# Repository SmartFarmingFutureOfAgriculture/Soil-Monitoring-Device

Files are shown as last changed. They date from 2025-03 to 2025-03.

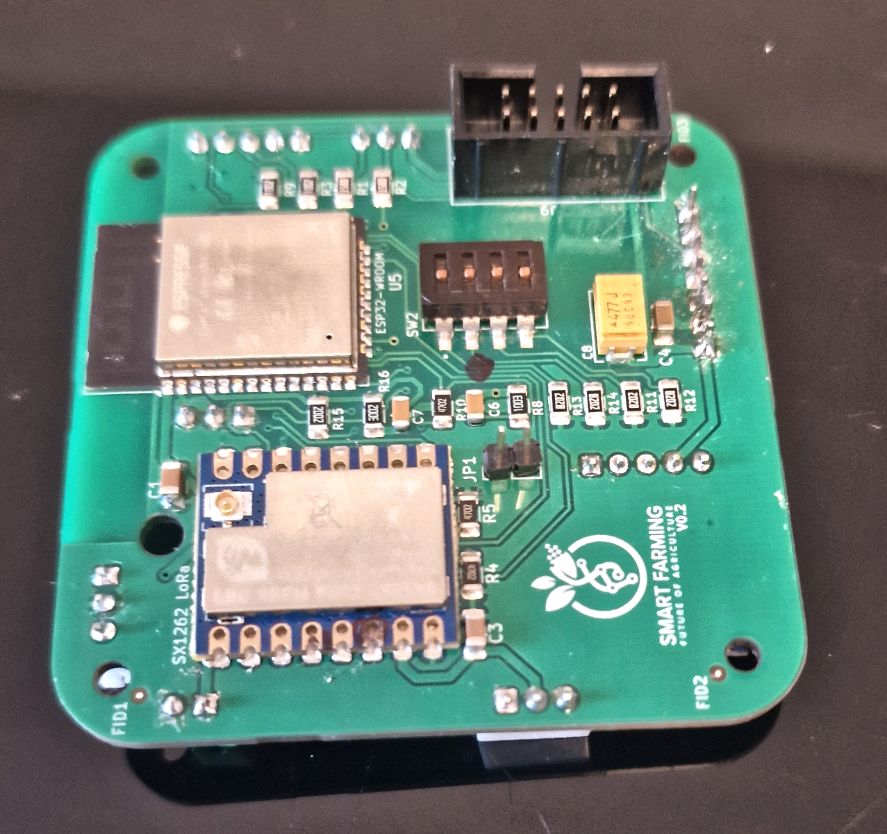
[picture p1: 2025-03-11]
hardware/gateway/5-Sensor-Node-Gateway-Top.jpg

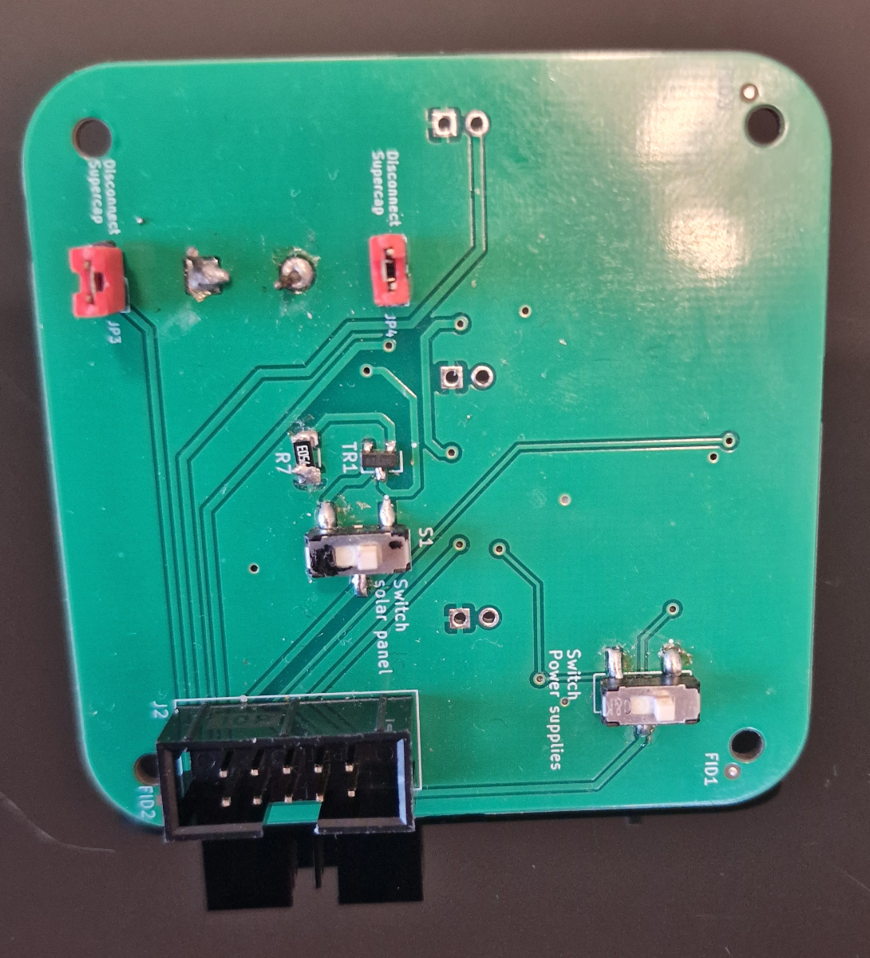
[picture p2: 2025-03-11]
hardware/power-supply/4-Power-Supply-Bottom.jpg

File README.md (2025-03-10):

# Smart Farming Soil Monitoring Device
This is an **open-source soil monitoring system** designed to measure NPK levels, temperature, moisture, and conductivity.

🚧 **Project Status: In Development** 🚧  
This project is still in the **development phase** and may change frequently.  
Some features may not be fully implemented, and modifications are ongoing.  
Contributions and feedback are welcome!  

## License
- **Software**: GNU GPL-2.0  
- **Hardware**: CERN OHL  
- **Disclaimer**: This project is provided **"as is"**, without any warranty or liability.

## How to Contribute
Contributions are welcome! Please follow the licensing rules and give proper attribution.

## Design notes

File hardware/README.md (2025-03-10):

## 🛠️ Hardware Development Tools
The hardware design files were created using:

- **KiCAD 6.x+** (for schematics & PCB design) → [https://www.kicad.org/](https://www.kicad.org/)
- **FreeCAD** (for 3D enclosure modeling) → [https://www.freecadweb.org/](https://www.freecadweb.org/)

💡 To modify the hardware, install **KiCAD** and **FreeCAD**, then open the project files.

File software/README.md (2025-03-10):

## 🔧 Software Development Tools
This project was developed using the following software:

- **PlatformIO** (for firmware development) → [https://platformio.org/](https://platformio.org/)
- **Arduino IDE** (alternative for testing) → [https://www.arduino.cc/en/software](https://www.arduino.cc/en/software)
- **Python 3.x** (for data processing scripts) → [https://www.python.org/](https://www.python.org/)

💡 To contribute or modify the software, install **PlatformIO** and clone the repository.

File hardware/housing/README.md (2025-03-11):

The housing can be produced with a 3D printer. The hardware design files were created using:

    FreeCAD (for 3D enclosure modeling) → https://www.freecadweb.org/

💡 To modify the hardware, install FreeCAD, then open the project files.

Smart Farming Soil Monitoring System
Copyright (C) 2024 Smart Farming gGmbH

This hardware design is released under the CERN Open Hardware License (CERN OHL).
You are free to use, modify, and distribute it under the terms of this license.
NO WARRANTY: This hardware is provided "as is", without any warranty of any kind.
The developer assumes no liability for damages resulting from its use.

For full license details, visit: https://ohwr.org/project/cernohl/wikis/home

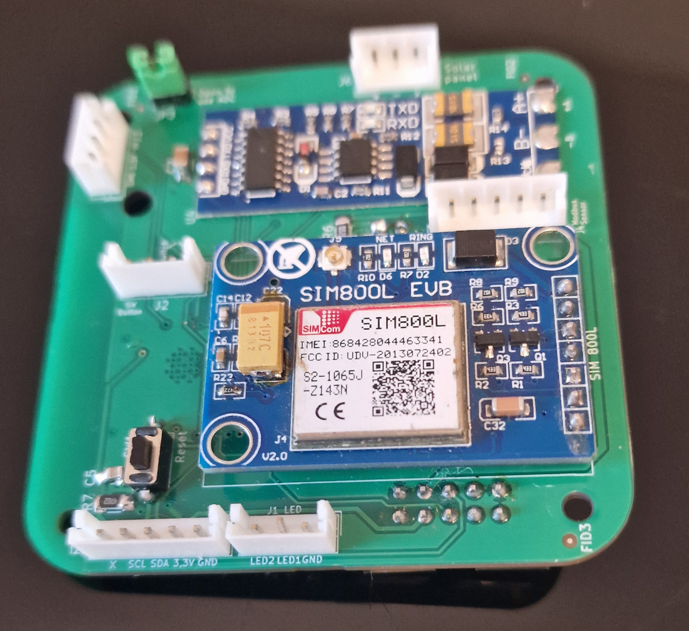
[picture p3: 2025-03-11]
hardware/gateway/6-Sensor-Node-Gateway-Bottom.jpg

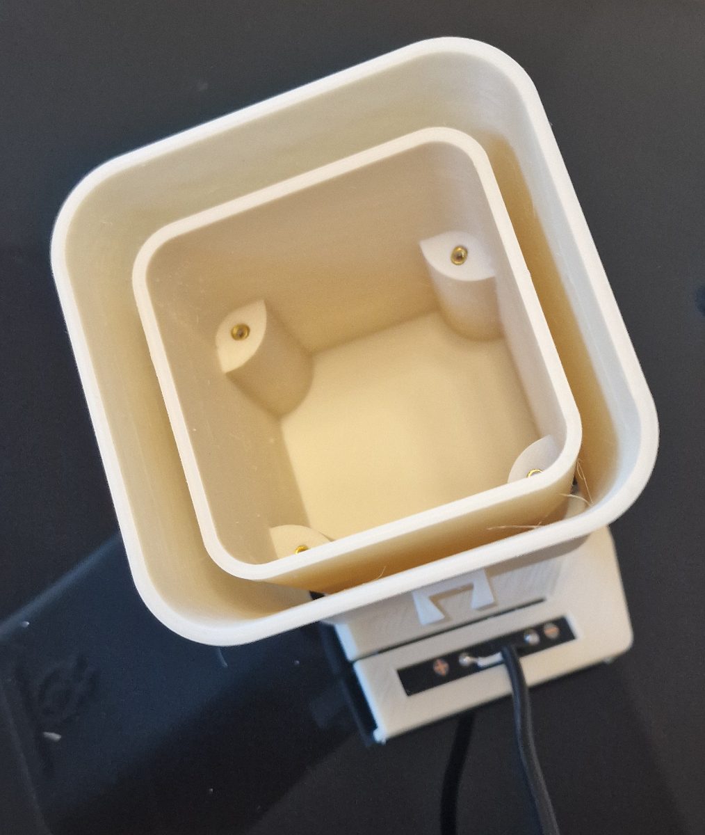
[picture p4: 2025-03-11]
hardware/housing/2-Housing-bottom.jpg

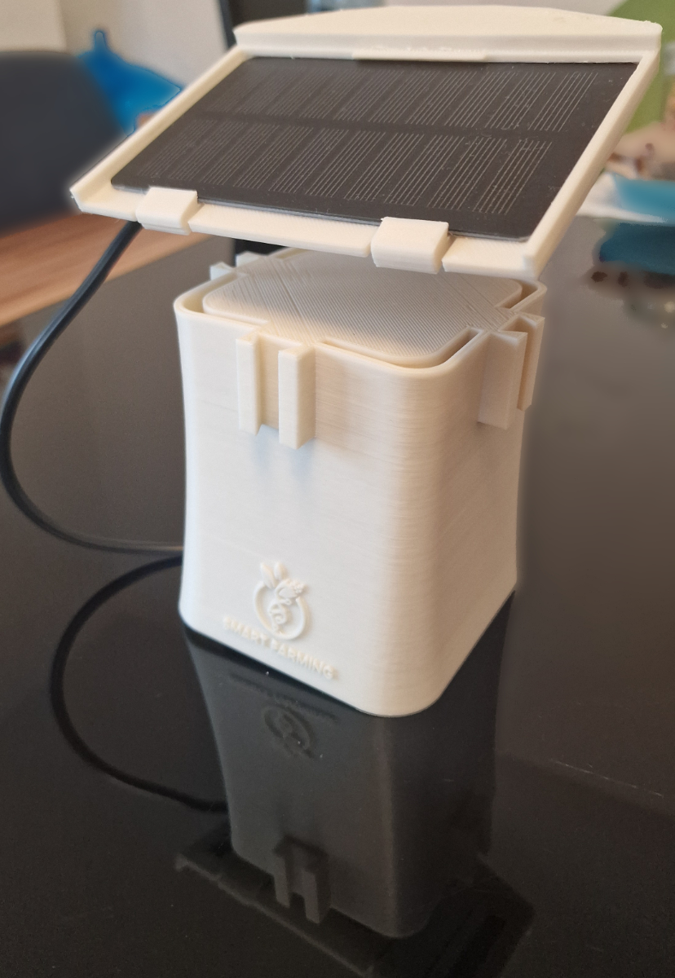
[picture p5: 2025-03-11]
hardware/housing/1-Housing.jpg

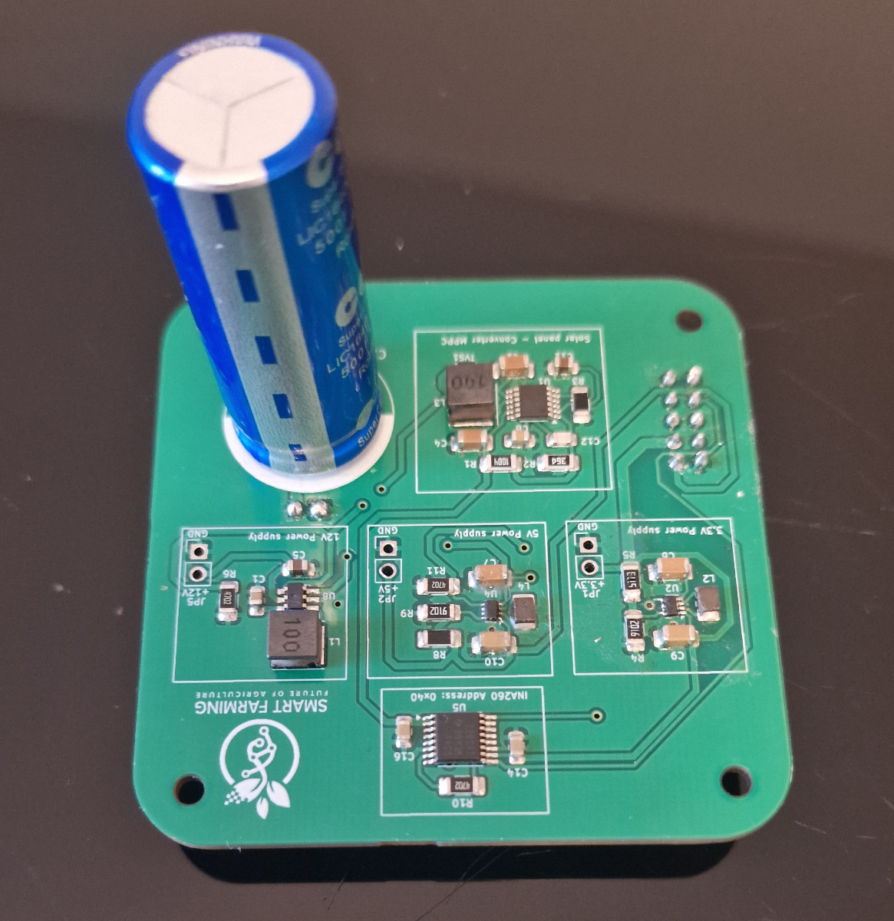
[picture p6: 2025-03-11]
hardware/power-supply/3-Power-Supply-Top.jpg

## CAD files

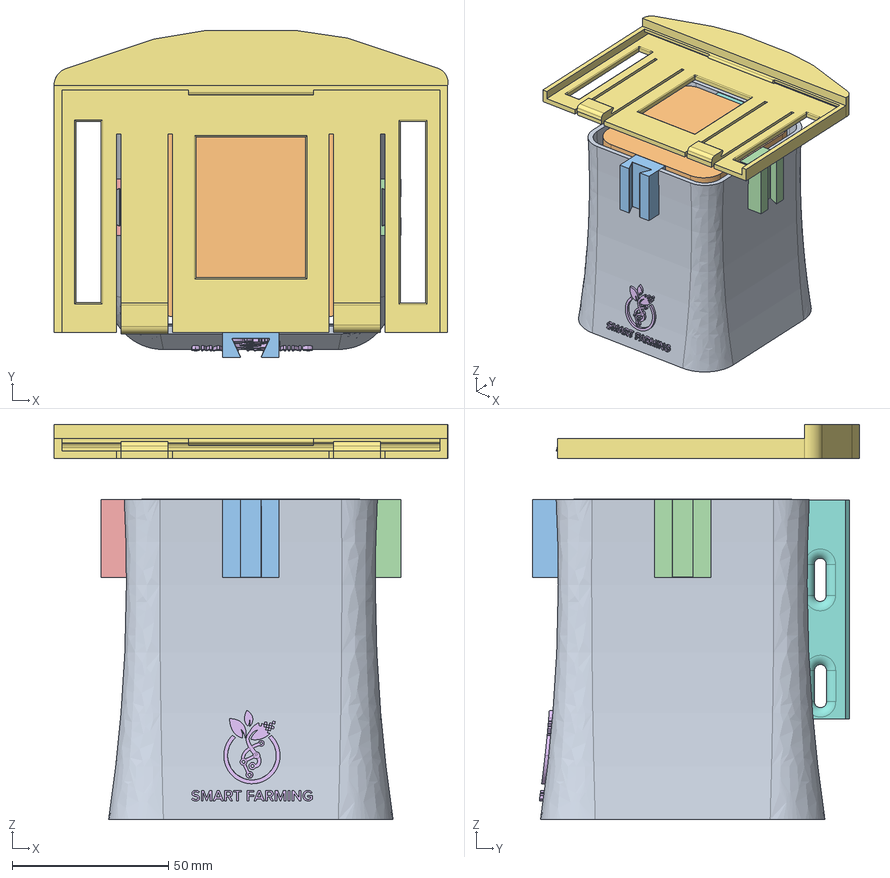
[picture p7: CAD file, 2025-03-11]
hardware/housing/Housing-Field-Sensor-Fixed-Solar-Holder.FCStd
126.1 x 104.5 x 126.5 mm
OuterContainer
InnerContainer
Projektionsobjekt_Logo
SolarHolder
Cut001_HousingHolder

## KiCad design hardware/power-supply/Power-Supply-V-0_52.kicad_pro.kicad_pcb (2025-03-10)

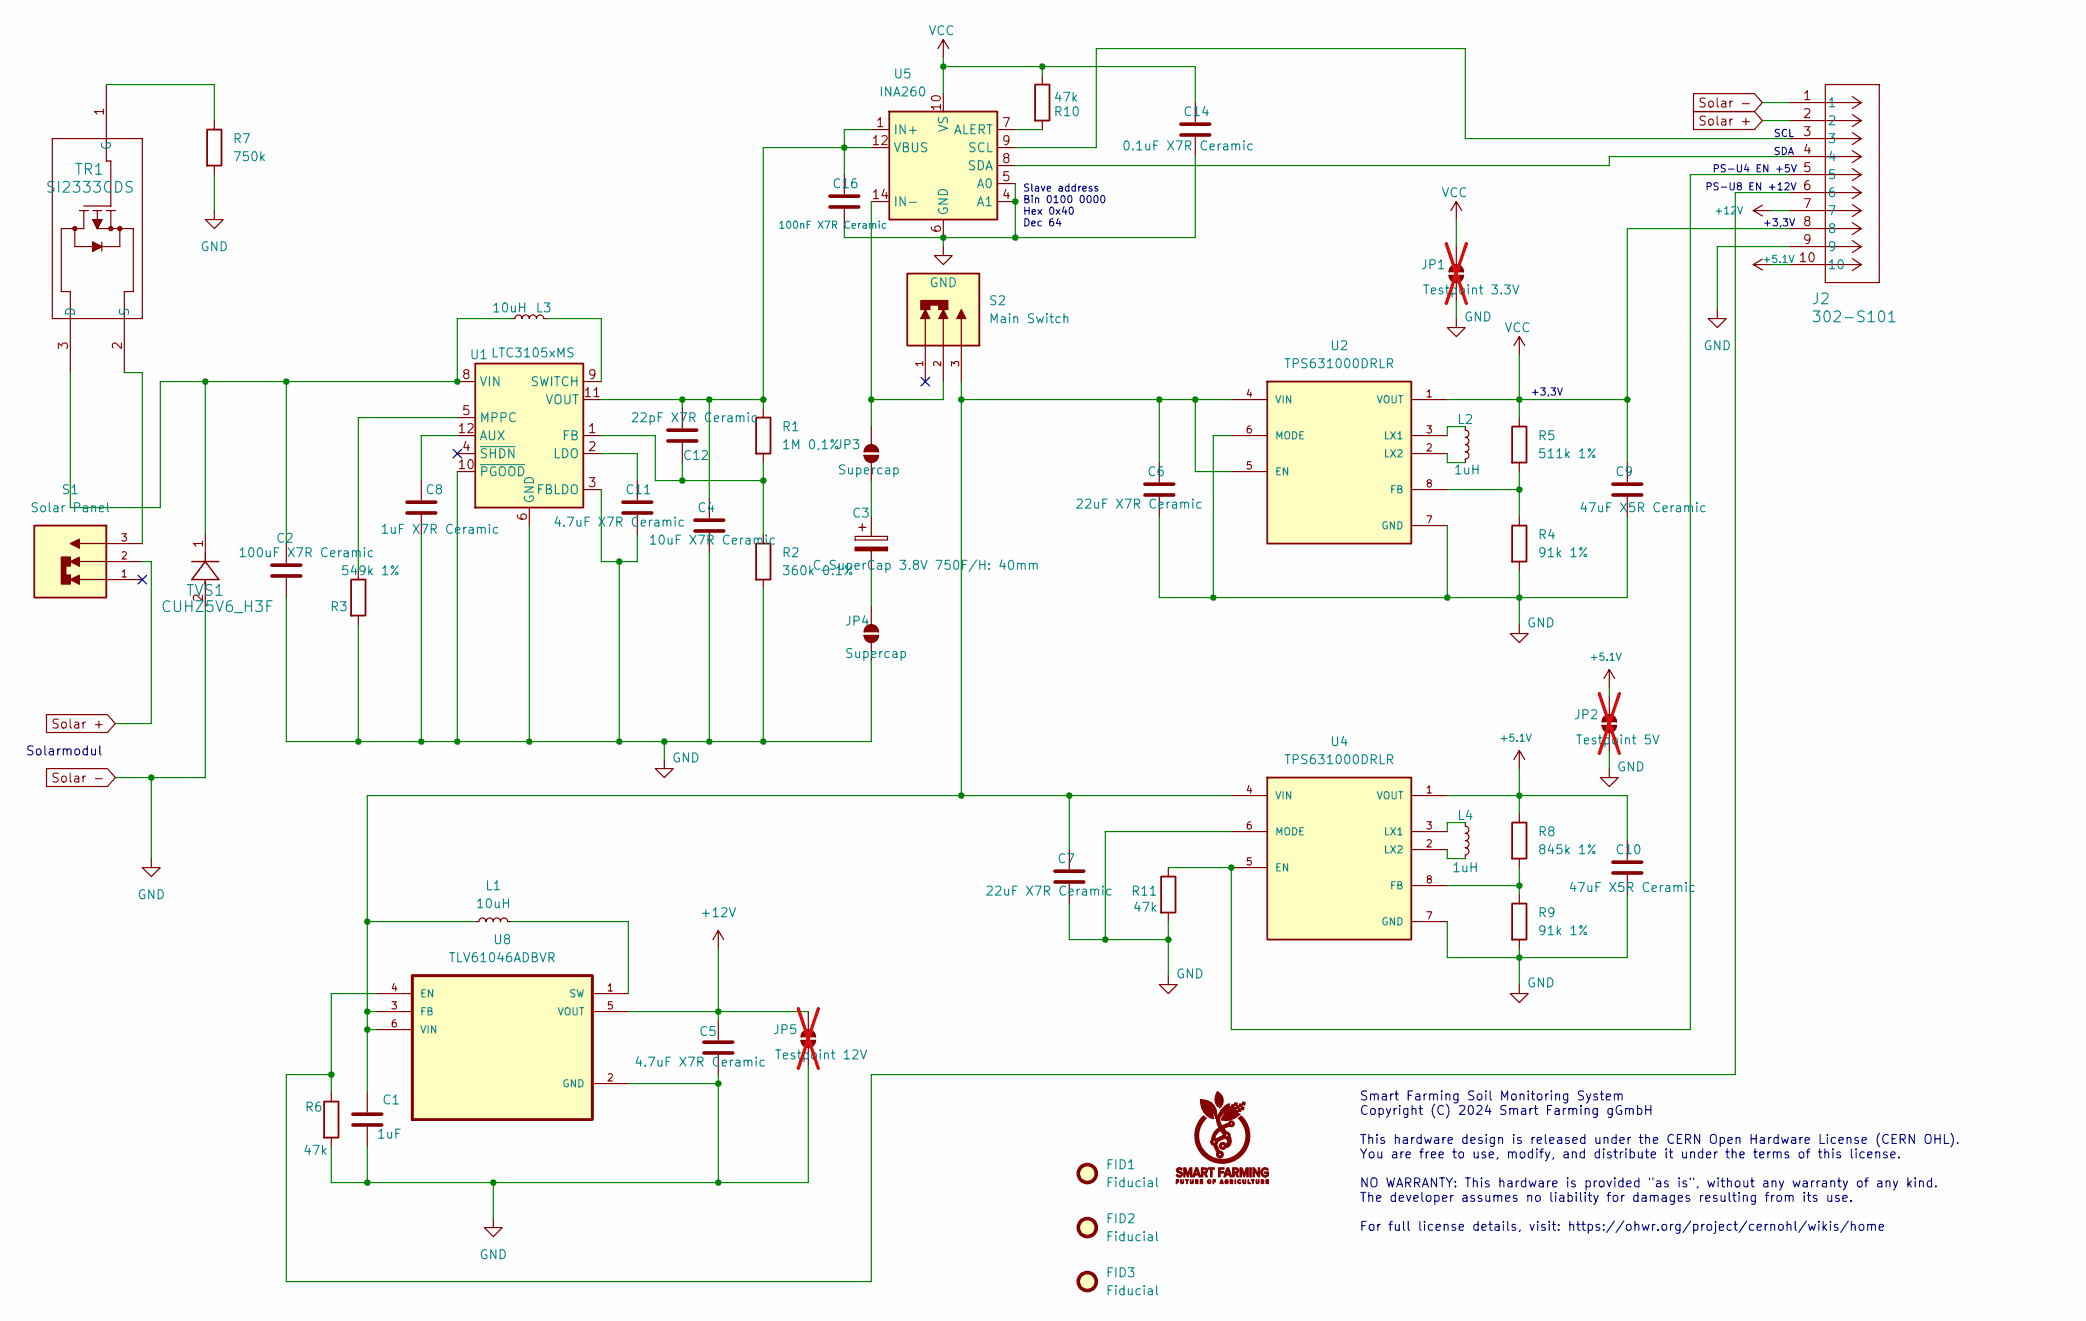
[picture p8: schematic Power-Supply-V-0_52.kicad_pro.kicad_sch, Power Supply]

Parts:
C1: 1uF; C_0805_2012Metric_Pad1.18x1.45mm_HandSolder
C2: 100uF X7R Ceramic; C_1206_3216Metric_Pad1.33x1.80mm_HandSolder
C3: C_SuperCap 3.8V 750F/H: 40mm; CP_Radial_D18.0mm_P7.50mm
C4: 10uF X7R Ceramic; C_1206_3216Metric_Pad1.33x1.80mm_HandSolder
C5, C11: 4.7uF X7R Ceramic; C_0805_2012Metric_Pad1.18x1.45mm_HandSolder
C6, C7: 22uF X7R Ceramic; C_1206_3216Metric_Pad1.33x1.80mm_HandSolder
C8: 1uF X7R Ceramic; C_0805_2012Metric_Pad1.18x1.45mm_HandSolder
C9, C10: 47uF X5R Ceramic; C_1206_3216Metric_Pad1.33x1.80mm_HandSolder
C12: 22pF X7R Ceramic; C_0805_2012Metric_Pad1.18x1.45mm_HandSolder
C14: 0.1uF X7R Ceramic; C_0805_2012Metric_Pad1.18x1.45mm_HandSolder
C16: 100nF X7R Ceramic; C_0805_2012Metric_Pad1.18x1.45mm_HandSolder
FID1, FID2, FID3: Fiducial; Fiducial_0.75mm_Mask1.5mm
J2: 302-S101; CONN10_302-S101_OST
JP1: Testpoint 3.3V; PinHeader_1x02_P2.54mm_Vertical; not fitted
JP2: Testpoint 5V; PinHeader_1x02_P2.54mm_Vertical; not fitted
JP3, JP4: Supercap; PinHeader_1x02_P2.54mm_Vertical
JP5: Testpoint 12V; PinHeader_1x02_P2.54mm_Vertical; not fitted
L1, L3: 10uH; L_Taiyo-Yuden_MD-5050
L2, L4: 1uH; L_1008_2520Metric_Pad1.43x2.20mm_HandSolder
R1: 1M 0,1%; R_1206_3216Metric_Pad1.30x1.75mm_HandSolder
R2: 360k 0.1%; R_1206_3216Metric_Pad1.30x1.75mm_HandSolder
R3: 549k 1%; R_1206_3216Metric_Pad1.30x1.75mm_HandSolder
R4, R9: 91k 1%; R_1206_3216Metric_Pad1.30x1.75mm_HandSolder
R5: 511k 1%; R_1206_3216Metric_Pad1.30x1.75mm_HandSolder
R6, R10, R11: 47k; R_1206_3216Metric_Pad1.30x1.75mm_HandSolder
R7: 750k; R_1206_3216Metric_Pad1.30x1.75mm_HandSolder
R8: 845k 1%; R_1206_3216Metric_Pad1.30x1.75mm_HandSolder
S1: Solar Panel; SW_JS102011SCQN; PARTREV 8 Oct 21
S2: Main Switch; SW_JS102011SCQN; PARTREV 8 Oct 21
TR1: SI2333CDS; TO-236_VIS
TVS1: CUHZ5V6_H3F; SOD-323HEUS2H_TOS
U1: LTC3105xMS; MSOP-12_3x4mm_P0.65mm
U2, U4: TPS631000DRLR; SOT-583-8; PARTREV B
U5: INA260; TSSOP-16_4.4x5mm_P0.65mm
U8: TLV61046ADBVR; SOT-23-6_Handsoldering

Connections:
+5.1V: C10.1, J2.10, JP2.2 (B), R8.1, U4.1 (VOUT)
+12V: C5.1, J2.7, JP5.2 (B), U8.5 (VOUT)
unnamed: C3.1, JP3.1 (A)
unnamed: JP3.2 (B), S2.2, U5.14 (IN-), U5.15 (IN-), U5.16 (IN-)
unnamed: C3.2, JP4.2 (B)
unnamed: C2.1, L3.1, TR1.3 (D), TVS1.1, U1.8 (VIN)
unnamed: R7.1, TR1.1 (G)
unnamed: S1.3, TR1.2 (S)
unnamed: C8.1, U1.12 (AUX)
unnamed: C12.2, R1.2, R2.1, U1.1 (FB)
unnamed: C11.1, U1.2 (LDO)
unnamed: R3.1, U1.5 (MPPC)
unnamed: L3.2, U1.9 (SWITCH)
unnamed: C4.1, C12.1, C16.1, R1.1, U1.11 (VOUT), U5.1 (IN+), U5.2 (IN+), U5.3 (IN+), U5.12 (VBUS)
unnamed: C1.1, C6.1, C7.1, L1.1, S2.3, U2.4 (VIN), U2.5 (EN), U4.4 (VIN), U8.3 (FB), U8.6 (VIN)
unnamed: R4.1, R5.2, U2.8 (FB)
unnamed: L2.1, U2.3 (LX1)
unnamed: L2.2, U2.2 (LX2)
unnamed: J2.5, R11.1, U4.5 (EN)
unnamed: R8.2, R9.1, U4.8 (FB)
unnamed: L4.1, U4.3 (LX1)
unnamed: L4.2, U4.2 (LX2)
unnamed: R10.2, U5.7 (ALERT)
unnamed: J2.3, U5.9 (SCL)
unnamed: J2.4, U5.8 (SDA)
unnamed: J2.6, R6.1, U8.4 (EN)
unnamed: L1.2, U8.1 (SW)
Solar +: J2.2, S1.2
Solar -: C1.2, C2.2, C4.2, C5.2, C6.2, C7.2, C8.2, C9.2, C10.2, C11.2, C14.2, C16.2, J2.1, J2.9, JP1.1 (A), JP2.1 (A), JP4.1 (A), JP5.1 (A), R2.2, R3.2, R4.2, R6.2, R7.2, R9.2, R11.2, TVS1.2, U1.3 (FBLDO), U1.6 (GND), U1.7 (GND), U1.10 (~PGOOD), U2.6 (MODE), U2.7 (GND), U4.6 (MODE), U4.7 (GND), U5.4 (A1), U5.5 (A0), U5.6 (GND), U5.11 (GND), U8.2 (GND)
VCC: C9.1, C14.1, J2.8, JP1.2 (B), R5.1, R10.1, U2.1 (VOUT), U5.10 (VS)

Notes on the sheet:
PS-U4 EN +5V
SCL
Smart Farming Soil Monitoring System Copyright (C) 2024 Smart Farming gGmbH This hardware design is released under the CERN Open Hardware License (CERN OHL). You are free to use, modify, and distribute it under the terms of this license. NO WARRANTY: This hardware is provided "as is", without any w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
Solarmodul
SDA
PS-U8 EN +12V
Slave address Bin 0100 0000 Hex 0x40 Dec 64
+3,3V

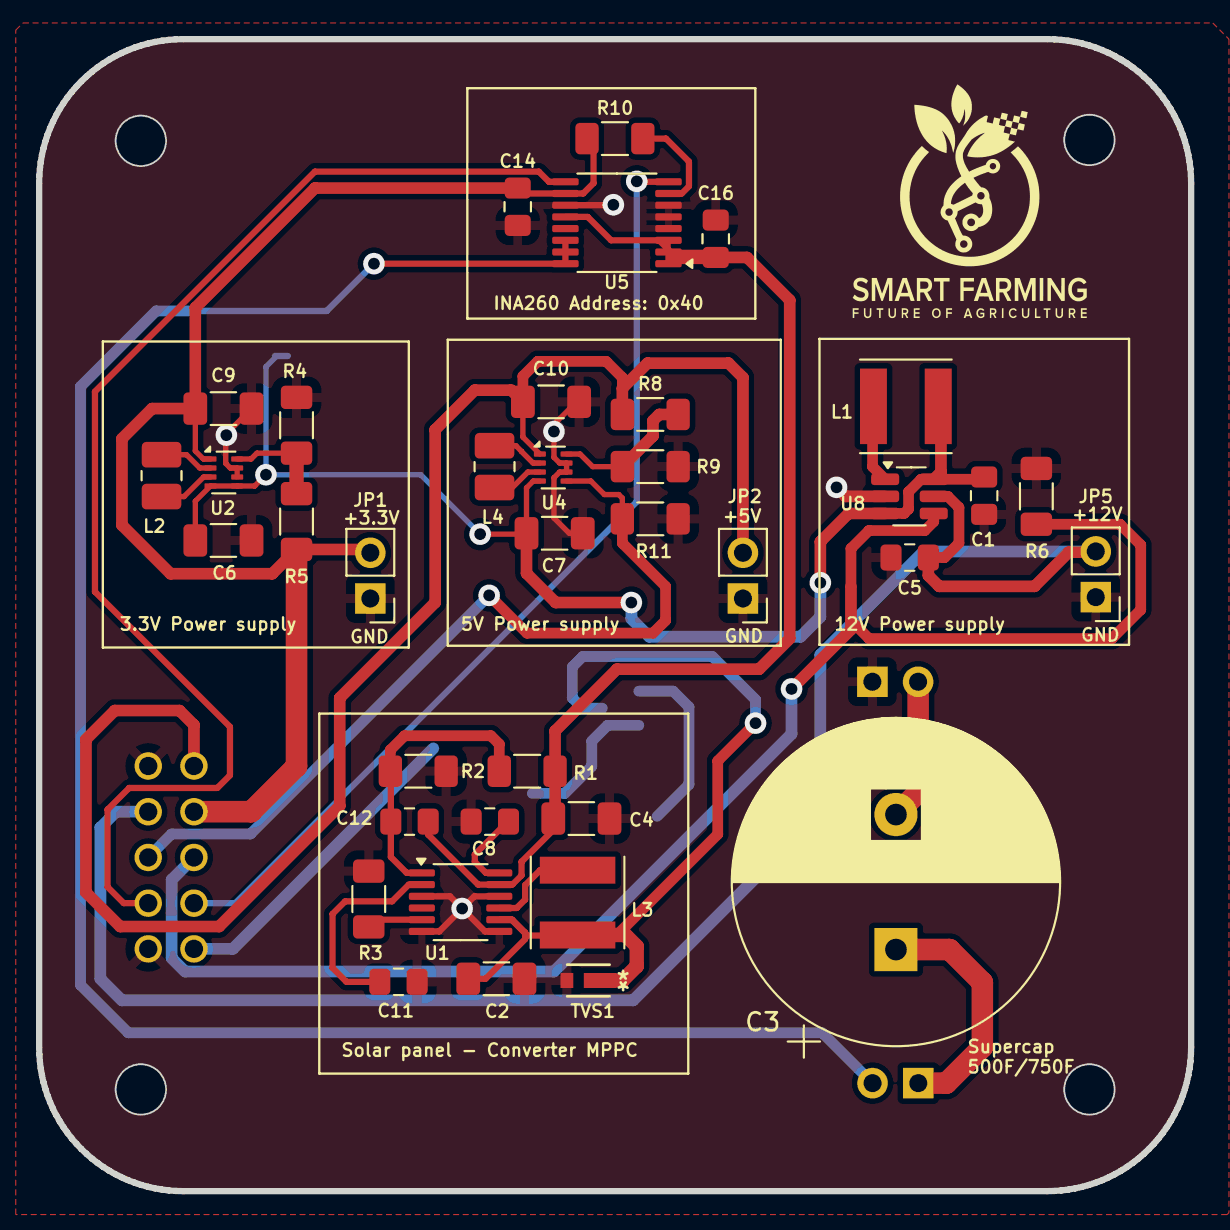
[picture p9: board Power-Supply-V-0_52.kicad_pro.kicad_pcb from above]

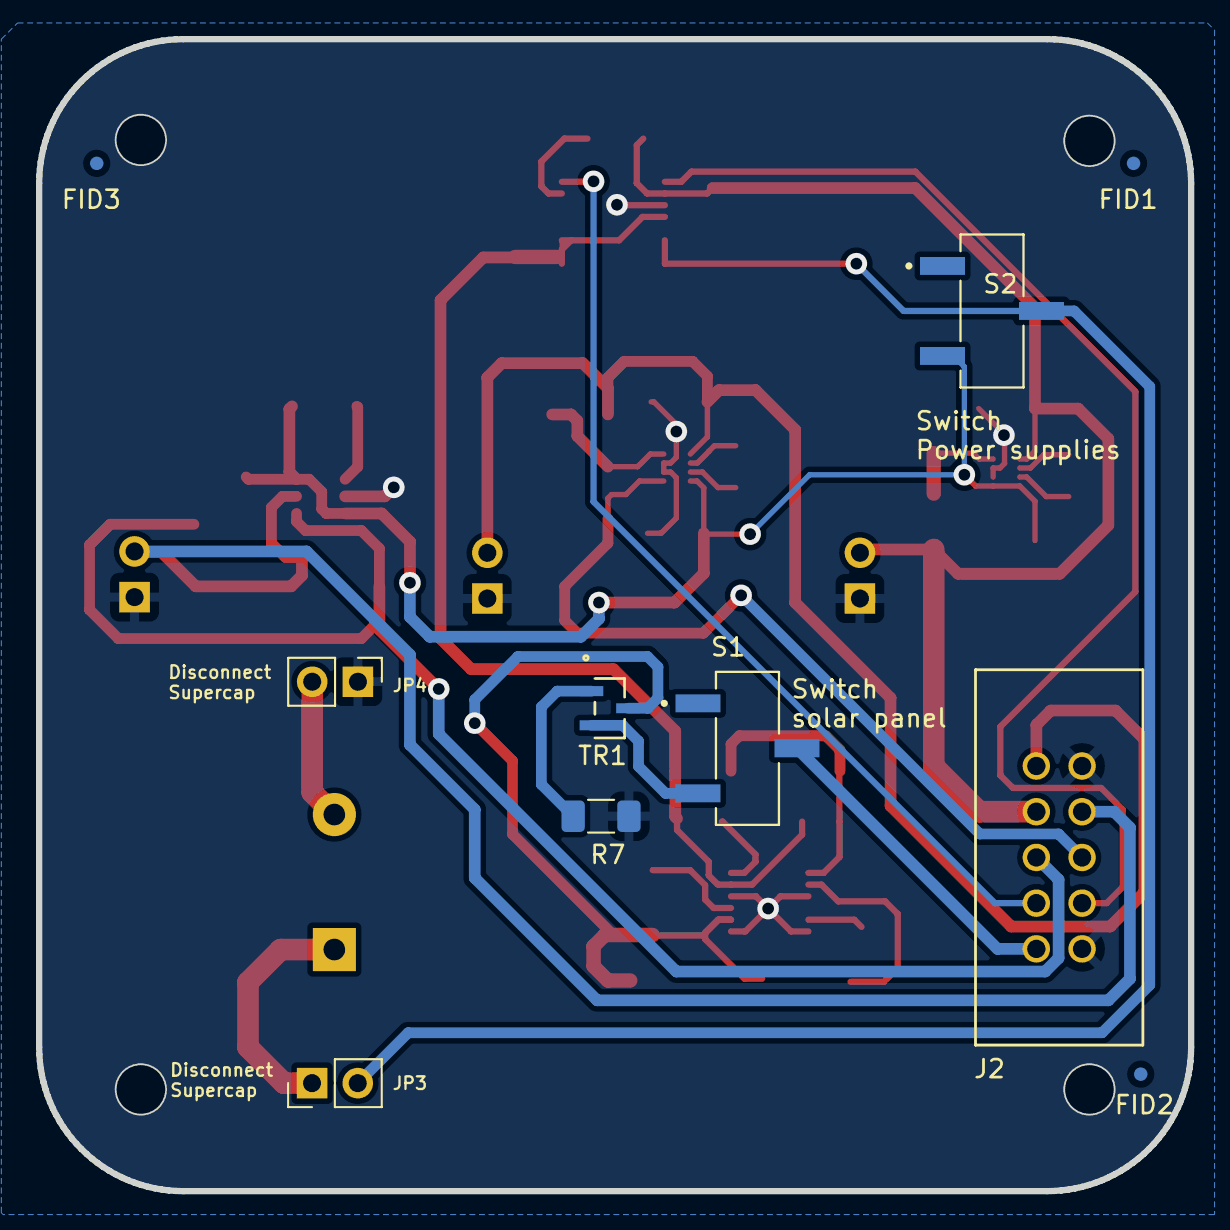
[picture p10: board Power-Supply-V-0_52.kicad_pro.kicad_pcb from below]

Board: 2 copper layers, 64.0 x 64.0 mm, 48 parts (10 on the bottom side), 30 nets.

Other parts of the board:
G**: LOGO; Logo_Smart_Farming

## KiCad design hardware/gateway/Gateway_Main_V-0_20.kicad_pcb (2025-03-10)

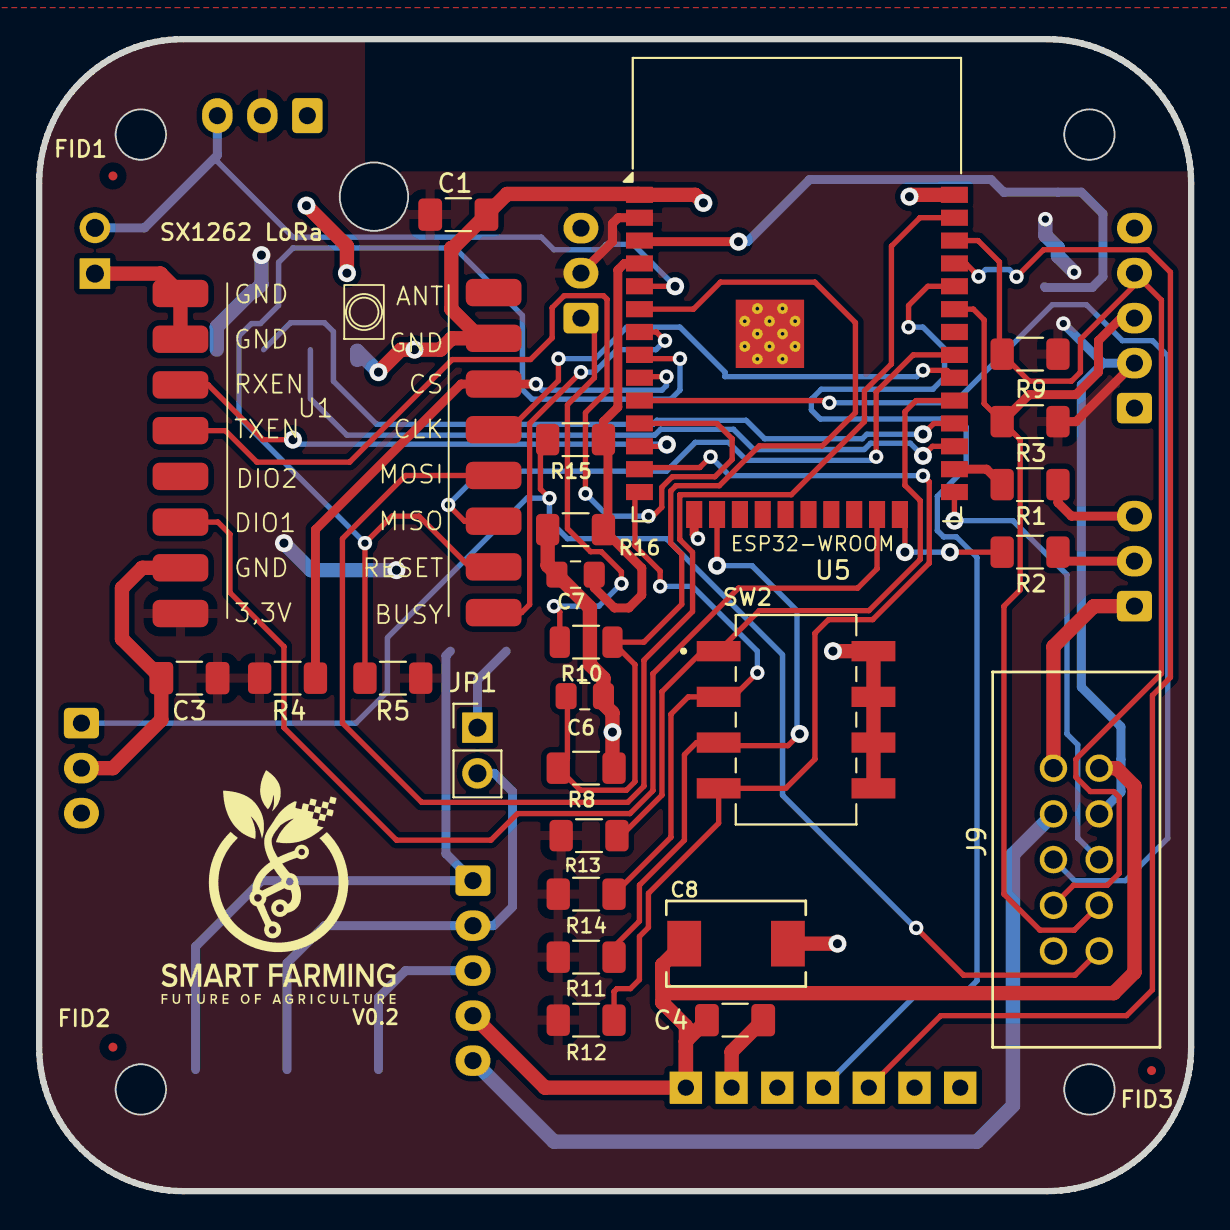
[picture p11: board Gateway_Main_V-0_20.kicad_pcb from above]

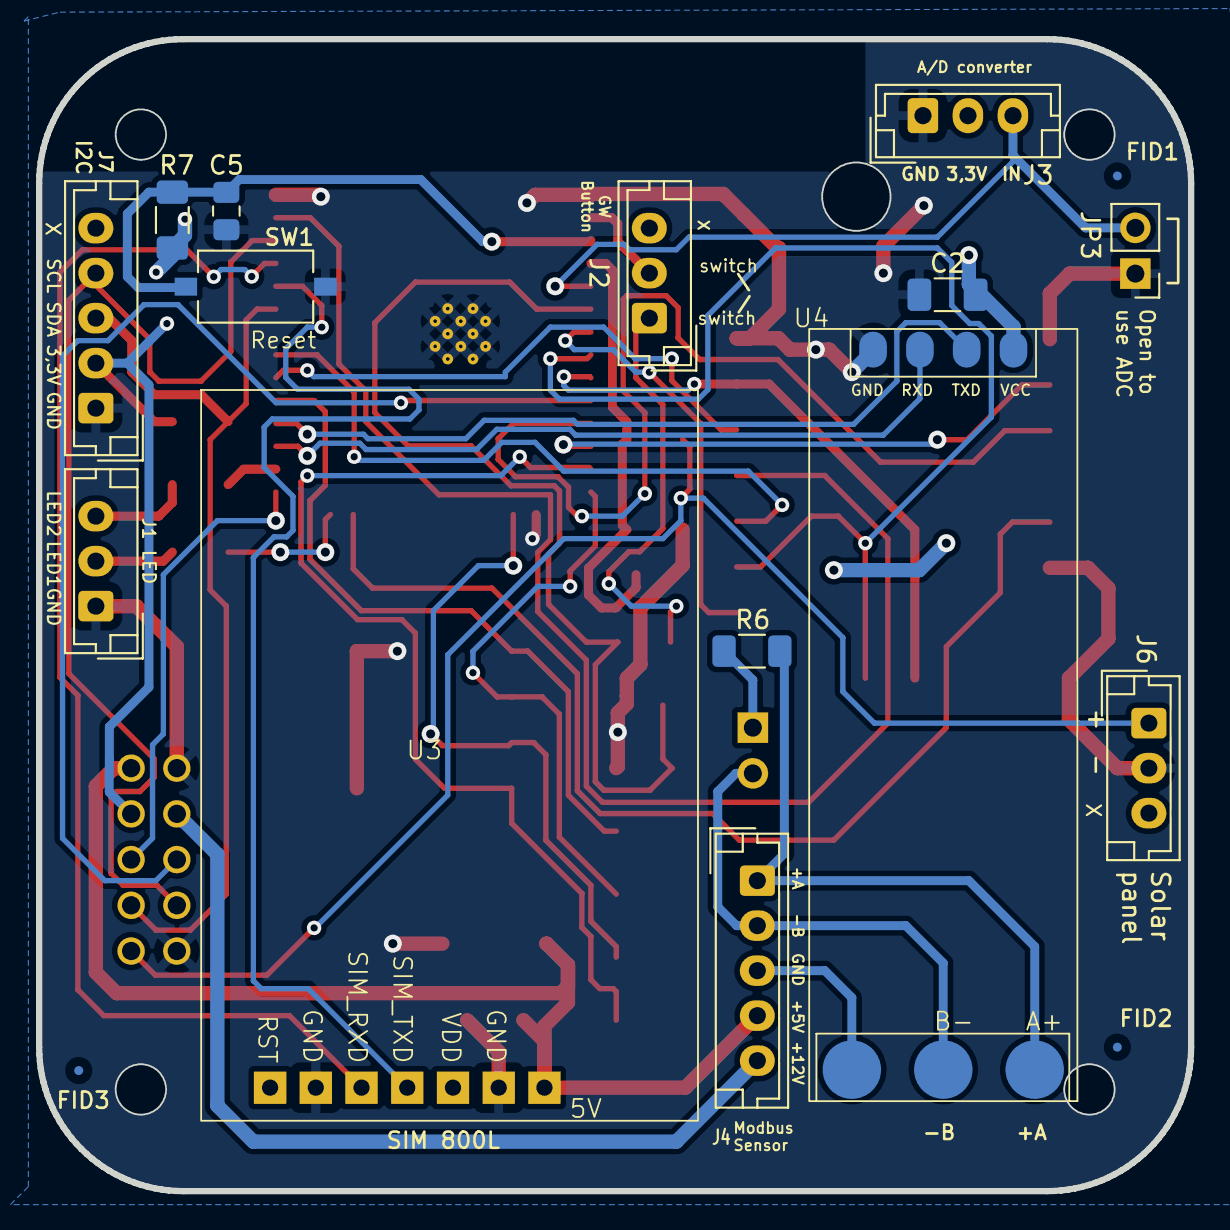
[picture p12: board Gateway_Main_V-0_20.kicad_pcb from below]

Board: 2 copper layers, 64.0 x 64.0 mm, 45 parts (17 on the bottom side), 39 nets.

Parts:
C1, C2, C3: 10uF X7R Ceramic; C_1206_3216Metric_Pad1.33x1.80mm_HandSolder
C4: 100uF; C_1206_3216Metric_Pad1.33x1.80mm_HandSolder
C5: 1uF; C_0805_2012Metric_Pad1.18x1.45mm_HandSolder
C6, C7: 0.1uF; C_0805_2012Metric_Pad1.18x1.45mm_HandSolder
C8: 470uF; TAJD_AVX
FID1, FID1#2, FID2, FID2#2, FID3, FID3#2: Fiducial; Fiducial_0.5mm_Mask1.5mm
J1: LED; JST_EH_B3B-EH-A_1x03_P2.50mm_Vertical
J2: Gateway button; JST_EH_B3B-EH-A_1x03_P2.50mm_Vertical
J3: A/D converter; JST_EH_B3B-EH-A_1x03_P2.50mm_Vertical
J4: Modbus (Sensor); JST_EH_B5B-EH-A_1x05_P2.50mm_Vertical
J6: Solar module; JST_EH_B3B-EH-A_1x03_P2.50mm_Vertical
J7: I2C; JST_EH_B5B-EH-A_1x05_P2.50mm_Vertical
J9: 302-S101; CONN10_302-S101_OST
JP1: Jumper_2_Bridged; PinHeader_1x02_P2.54mm_Vertical
JP3: ADC1_CH3; PinHeader_1x02_P2.54mm_Vertical
R1, R2: 150; R_1206_3216Metric_Pad1.30x1.75mm_HandSolder
R3, R9: 10k; R_1206_3216Metric_Pad1.30x1.75mm_HandSolder
R4, R5, R7: 47k; R_1206_3216Metric_Pad1.30x1.75mm_HandSolder
R6: 120; R_1206_3216Metric_Pad1.30x1.75mm_HandSolder
R8: 100k; R_1206_3216Metric_Pad1.30x1.75mm_HandSolder
R10: 47k; R_1206_3216Metric
R11, R12, R13, R14: 82k; R_1206_3216Metric_Pad1.30x1.75mm_HandSolder
R15: 20k 1%; R_1206_3216Metric_Pad1.30x1.75mm_HandSolder
R16: 30k 1%; R_1206_3216Metric_Pad1.30x1.75mm_HandSolder
SW1: Reset; SW_Tactile_SPST_NO_Straight_CK_PTS636Sx25SMTRLFS
SW2: SW-219-4MST; Switch-SW_219-4MST
U1: CORE1262-868M; SX1262_LoRa_NODE
U3: SIM800L; SIM800L_EVB-MODULE
U4: TTL to RS485; RS485_To_TTL
U5: ESP32-WROOM-32E; ESP32-WROOM-32D

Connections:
+3.3V: C1.1, C2.1, C3.1, J2.2, J3.2, J7.2, J9.7, R3.1, R4.1, R5.1, R7.1, R9.1, R11.1, R12.1, R13.1, R14.1, U1.8 (3V3), U4.4 (Vcc), U5.2 (VDD)
+5V: C4.1, C8.1, J4.4, J9.9, U3.1 (5V)
+12V: J4.5, J9.8
GND: C1.2, C2.2, C3.2, C4.2, C5.2, C6.2, C7.2, C8.2, J1.1, J3.1, J6.2, J7.1, J9.2, J9.10, JP3.1 (A), R8.2, R16.2, SW1.2, SW2.5, SW2.6, SW2.7, SW2.8, U1.1 (GND), U1.2 (GND), U1.7 (GND), U1.15 (GND), U3.2 (GND), U3.6 (GND), U4.1 (GND), U5.1 (GND), U5.15 (GND), U5.38 (GND), U5.39 (GND)
unnamed: J1.2, R2.2
unnamed: J1.3, R1.2
unnamed: J2.1, R10.1
unnamed: J3.3, JP3.2 (B), U5.5 (SENSOR_VN)
unnamed: J4.1, R6.2, U4.5 (A+)
unnamed: J4.2, JP1.2 (B), U4.6 (B-)
unnamed: J4.3, U4.7 (GND2)
unnamed: J6.1, J9.1, R15.1
unnamed: J7.3, J9.3, R3.2, U5.33 (IO21)
unnamed: J7.4, J9.4, R9.2, U5.36 (IO22)
unnamed: JP1.1 (A), R6.1
unnamed: U1.9 (BUSY), U5.7 (IO35)
unnamed: U1.13 (CLK), U5.30 (IO18)
unnamed: R4.2, U1.14 (CS), U5.9 (IO33)
unnamed: U1.6 (DIO1), U5.23 (IO15)
unnamed: U1.11 (MISO), U5.31 (IO19)
unnamed: U1.12 (MOSI), U5.37 (IO23)
unnamed: R5.2, U1.10 (RESET), U5.8 (IO32)
unnamed: U1.3 (RXEN), U5.12 (IO27)
unnamed: U1.4 (TXEN), U5.11 (IO26)
unnamed: U3.5 (SIM_RXD), U5.35 (TXD0/IO1)
unnamed: U3.4 (SIM_TXD), U5.34 (RXD0/IO3)
unnamed: U4.2 (RxD), U5.27 (IO16)
unnamed: U4.3 (TxD), U5.28 (IO17)
unnamed: C5.1, R7.2, SW1.1, U5.3 (EN)
unnamed: J9.5, U5.25 (IO0)
unnamed: R2.1, U5.24 (IO2)
unnamed: R1.1, U5.26 (IO4)
unnamed: R13.2, SW2.1, U5.29 (IO5)
unnamed: R14.2, SW2.2, U5.14 (IO12)
unnamed: R11.2, SW2.3, U5.16 (IO13)
unnamed: R12.2, SW2.4, U5.13 (IO14)
unnamed: J9.6, U5.10 (IO25)
unnamed: C6.1, R8.1, R10.2, U5.6 (IO34)
unnamed: C7.1, R15.2, R16.1, U5.4 (SENSOR_VP)

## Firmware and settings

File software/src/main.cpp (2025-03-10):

/*
 * Smart Farming Soil Monitoring System
 * Copyright (C) 2024 Smart Farming gGmbH
 *
 * This software is released under the GNU General Public License v2 (GPL-2.0).
 * You are free to use, modify, and distribute it under the terms of this license.
 *
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
 * See the full license at: https://www.gnu.org/licenses/old-licenses/gpl-2.0.en.html
 */


#include <Arduino.h>
#include <WiFiClientSecure.h>
#include "WiFiManager.h"
#include "SensorManager.h"
#include "ConfigManager.h"
#include "DataSender.h"
#include "SleepManager.h"
#include <config.h>

// Klasseninstanzen
WiFiManager wifiManager(ssid, password, client);
SensorManager sensorManager;
ConfigManager configManager(client);
DataSender dataSender(client);
SleepManager sleepManager;

void setup()
{
    // Reducing the frequency to save energy
    setCpuFrequencyMhz(80);

    Serial.begin(9600);
    delay(1000);

    // Load sensor configuration from storage
    if (!configManager.loadSensorConfig())
    {
        // ...if there is no data in the flash, get it from web server
        configManager.fetchSensorConfig();
    }

    // Static class variable "sensorConfigData" contains sensors' configuration
    configManager.distributeSensorsToManagers();

    // wifiManager.connect();

    // Determine the reason for waking up
    //if (configManager.shouldFetchConfig())
    //{
     //   configManager.fetchConfig();
    //}
    // Read sensor data
    String sensorDataJson = sensorManager.getSensorDataJson();
    // Send sensor data to webserver
    dataSender.sendSensorData(sensorDataJson);

    sleepManager.enterDeepSleep();
}

void loop() {}

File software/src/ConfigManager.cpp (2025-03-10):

/*
 * Smart Farming Soil Monitoring System
 * Copyright (C) 2024 Smart Farming gGmbH
 *
 * This software is released under the GNU General Public License v2 (GPL-2.0).
 * You are free to use, modify, and distribute it under the terms of this license.
 *
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
 * See the full license at: https://www.gnu.org/licenses/old-licenses/gpl-2.0.en.html
 */

#include <ArduinoJson.h>
#include "ConfigManager.h"
#include "esp_sleep.h"
#include <ArduinoJson.h>
// NVS storage for JASON data
#include <Preferences.h>
#include <config.h>

ConfigManager::ConfigManager(WiFiClientSecure &client) : client(client) {}

// JSON document for sensor configuration
DynamicJsonDocument sensorConfigData(2048);

// JSON data storage in Flash
Preferences preferences;

/**
 * @brief
 * Dectects the wakeup reason
 *
 * @return true (if wakeup was caused by reset or power up)
 * @return false (every other case)
 */
bool ConfigManager::shouldFetchConfig()
{
    uint64_t wakeup_reason = esp_sleep_get_wakeup_cause();
    return (wakeup_reason == ESP_SLEEP_WAKEUP_UNDEFINED);
}



/**
 * @brief Loading JSON data from Flash
 *
 * "sensorConfigData" holds the sensors' configuration data
 * @return true, if data is stored in the flash and serialization works
 * @return false, if no data is stored in the flash or serialization fails
 */
bool ConfigManager::loadSensorConfig()
{
    // Load the saved configuration named "sensor_config" and save it in "savedConfigRaw"
    preferences.begin("sensor_config", true);
    String savedConfigRaw = preferences.getString("config", "");
    preferences.end();

    // If there is no data in the flash
    if (savedConfigRaw == "")
        return false;

    // Deserialize JSON data for easy access to individual elements (saved in "sensorConfigData")
    DeserializationError error = deserializeJson(sensorConfigData, savedConfigRaw);
    if (error)
    {
        Serial.println("Error: " + (String)error.c_str());
        return false;
    }
    return true;
}
// end of function ----------------


/**
 * @brief Request JSON configuration file from a web server with PHP available
 *
 * - Sends an HTTP GET request to the address in configUrl on the server.
 * - Server processes the request and sends back the requested resource (JSON file)
 * - The response can then be read in and further processed by the client
 */
void ConfigManager::fetchConfig()
{
    // Provide SSL server certificate
    client.setCACert(root_ca);

    // Connect to the HTTP server
    if (!client.connect(server, httpsPort))
    {
        Serial.println("❌ Verbindung fehlgeschlagen!");
        return;
    }

    // Retrieve (GET) the contents from the file (from variable: configURL)
    client.print(String("GET ") + configUrl + " HTTP/1.1\r\n" +
                 "Host: " + server + "\r\n" +
                 "Connection: close\r\n\r\n");

    String jsonPayload;
    while (client.connected() || client.available())
    {
        String line = client.readStringUntil('\n');
        jsonPayload += line;
    }
    client.stop();

    // Stores the JSON data
    if (!saveSensorConfig(jsonPayload))
    {
        Serial.println("Error, can't save data in flash memory");
    }

    //  parseConfig(jsonPayload);
}
// end of function ----------------


/**
 * @brief Stores the JSON data from the web server in the ESP32's flash memory
 *
 * @param String jsonString
 *
 */
bool ConfigManager::saveSensorConfig(String jsonString)
{
    if (preferences.begin("sensor_config", false))
    {
        preferences.putString("config", jsonString);
        preferences.end();
        return true;
    }
    return false;
}
// end of function ----------------


/**
 * @brief 
 * 
 */
void distributeSensorsToManagers(void) {
    JsonArray sensors = sensorConfigData["shared"]["sensor_config"]["sensors"];

    // loop goes through each element from the sensors list and stores it in the variable sensor.
    for (JsonObject sensor : sensors) {
        String protocol = sensor["protocol"].as<String>();

        if (protocol == "I2C") {
            Serial.println("I2C-Sensor erkannt: " + sensor["name"].as<String>());
            I2CManager::registerSensor(sensor);
        }
        else if (protocol == "Modbus") {
            Serial.println("Modbus-Sensor erkannt: " + sensor["name"].as<String>());
            //ModbusManager::registerSensor(sensor);
        }
        else {
            // Insert another interface here
            Serial.println("Unbekanntes Protokoll für Sensor: " + sensor["name"].as<String>());
        }
    }
}


//*************************** */
void ConfigManager::parseConfig(const String &jsonPayload)
{
    DynamicJsonDocument doc(1024);
    DeserializationError error = deserializeJson(doc, jsonPayload);

    if (error)
    {
        Serial.print("❌ JSON-Fehler: ");
        Serial.println(error.f_str());
        return;
    }

    Serial.println("🌍 Gateway-Infos:");
    Serial.print("Name: ");
    Serial.println(doc["gateway"]["name"].as<String>());
    Serial.print("Ort: ");
    Serial.println(doc["gateway"]["title"].as<String>());
    Serial.print("Land: ");
    Serial.println(doc["gateway"]["country"].as<String>());

    Serial.println("\n🔎 Sensoren:");
    JsonArray sensors = doc["sensors"].as<JsonArray>();

    for (JsonVariant sensor : sensors)
    {
        Serial.println("--------------------");
        Serial.print("📡 Name: ");
        Serial.println(sensor["name"].as<String>());
        Serial.print("📝 Titel: ");
        Serial.println(sensor["title"].as<String>());
        Serial.print("⚡ Status: ");
        Serial.println(sensor["status"].as<String>());
        Serial.print("🔌 Schnittstelle: ");
        Serial.println(sensor["protocol"].as<String>());

        if (sensor["protocol"] == "I2C")
        {
            Serial.print("  ➝ I2C-Adresse: ");
            Serial.println(sensor["protocol_config"]["address"].as<String>());
            Serial.print("  ➝ I2C-Speed: ");
            Serial.println(sensor["protocol_config"]["speed"].as<String>());
        }
        else if (sensor["protocol"] == "Modbus")
        {
            Serial.print("  ➝ Modbus-Adresse: ");
            Serial.println(sensor["protocol_config"]["address"].as<int>());
            Serial.print("  ➝ Baudrate: ");
            Serial.println(sensor["protocol_config"]["baud_rate"].as<int>());
        }

        if (sensor["function"]["Plant_type"].is<String>())
        {
            Serial.print("🌱 Pflanzentyp: ");
            Serial.println(sensor["function"]["Plant_type"].as<String>());
            Serial.print("🪴 Wachstumsphase: ");
            Serial.println(sensor["function"]["Growth_stage"].as<String>());
            Serial.print("📅 Pflanzdatum: ");
            Serial.println(sensor["function"]["Planting_date"].as<String>());
        }
    }

    Serial.println("\n✅ Sensor-Konfiguration abgeschlossen!");
}
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
